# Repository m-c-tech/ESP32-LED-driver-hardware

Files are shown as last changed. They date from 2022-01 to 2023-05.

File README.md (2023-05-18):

# ESP32-LED-driver-hardware
A board to drive WRGB and addressable LEDs using a NodeMCU-32S ESP32 WiFi microcontroller development board.  

## Goals:
The goal for this project was to make an ESPHOME and Home Assistant compatible LED strip controller.  
Price is an important factor as well as ease of use and flexibility in its applications.  
[ESPHome](https://esphome.io/) is a software tool that can generate code for the ESP32 microcontrollers by using simple configuration files and [Home Assistant](https://www.home-assistant.io/) has a graphical interface to set up automations.  
This gives great flexibility with over-the-air updates and easy to understand setup.  
The ESP32 microcontroller is highly flexible with WiFi and bluetooth along with many GPIOs, ADCs, touch sensors, etc.  
Development boards for the ESP32 can be gotten for very cheap from various online sellers, pay close attention to the dev board pinouts as they can vary.  
This PCB design incorporates multiple resistor configurations to allow for differing types of LEDs to be driven, common anode, SPI, one wire.

## Software and costs:  
PCB design done in KICAD 6.0  
Mechanical enclosure design done in Autodesk Fusion 360.  
The bill of materials comes to roughly 20.70AUD per unit at quantaties of 20.  
This includes the ESP32 dev board ($6.75), components from digi-key ($7.80), PCBs from fab house ($2.27), 3D printer plastic ($1.60), plus a few other items.  

## Enclosure:  
Designed for 3D printing.  
Dimensions - (L) 56.6mm * (W) 56.6mm * (D) 26mm  
The enclosure needs a M3 heated nut-sert to be put in the lid and a countersunk M3 machine screw.  

## Power:  
Input power can be 5V to 12V up to 5A current.  
Input connector is a 2.1mm ID, 5.5mm OD, 9.5mm long barrel jack plug.  

## Pinouts:  
Pinout used for common anode RGBW 5/12V LEDs:  
VDD  - Power +ve  
IO19 - White  
IO18 - Red  
IO17 - Green  
IO16 - Blue  
GND	 - Unused  

Hardware changes for driving addressable LEDs:  
Remove 0R resistors from R1-R4.  
Place 0R resistors on R5-R7.  

Pinout for up to 4 strings of one wire addressable LEDs:  
VDD  - Power +ve (ensure your power supply is correct for your LED voltage)  
IO19 - LED data 1  
IO18 - LED data 2  
IO17 - LED data 3  
IO16 - LED data 4  
GND	 - GND  

Pinout used for 2 strings of SPI addressable LEDs:  
VDD  - Power +ve (ensure your power supply is correct for your LED voltage)  
IO19 - LED data 0  
IO18 - LED clock 0  
IO17 - LED data 1  
IO16 - LED clock 1  
GND	 - GND  

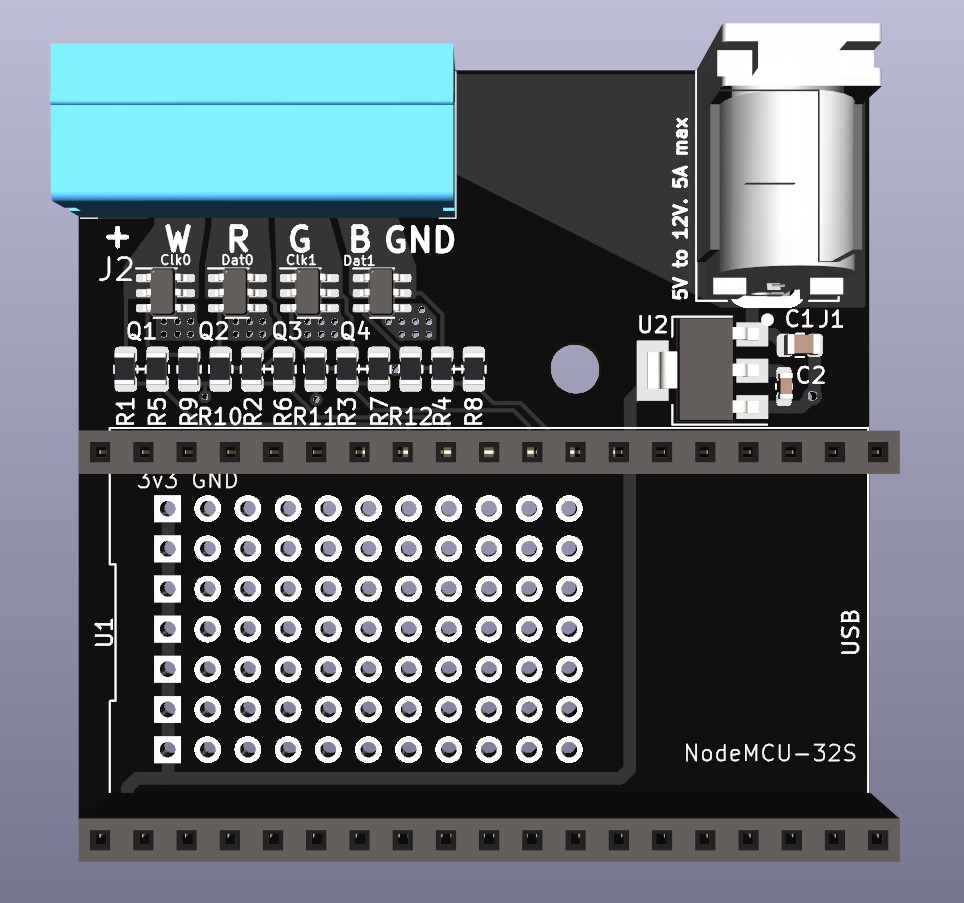
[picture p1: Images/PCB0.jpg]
PCB0

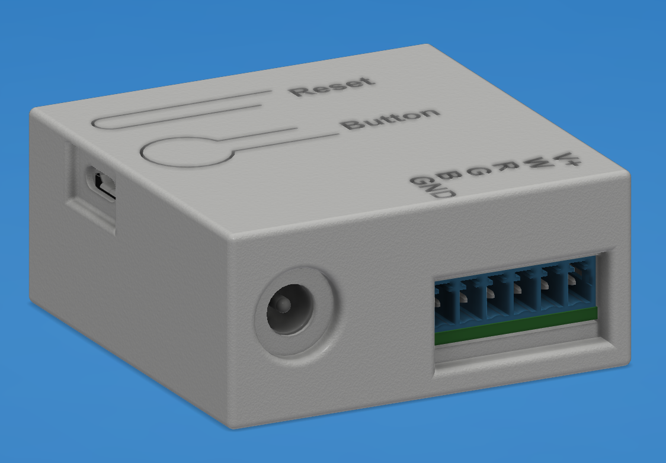
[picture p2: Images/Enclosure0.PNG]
Enclosure0

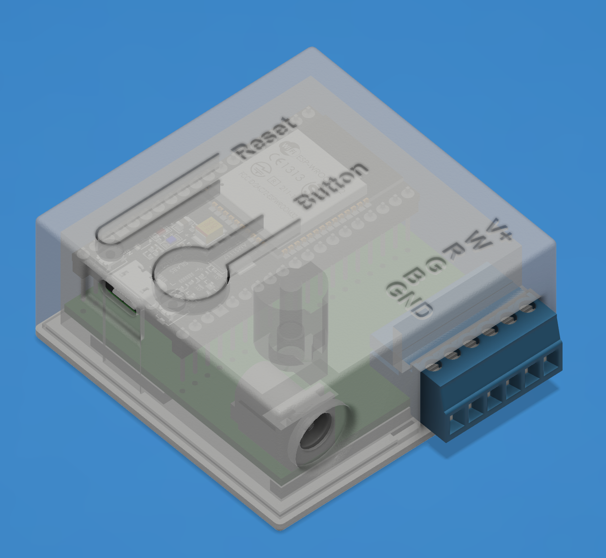
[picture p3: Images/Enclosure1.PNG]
Enclosure1


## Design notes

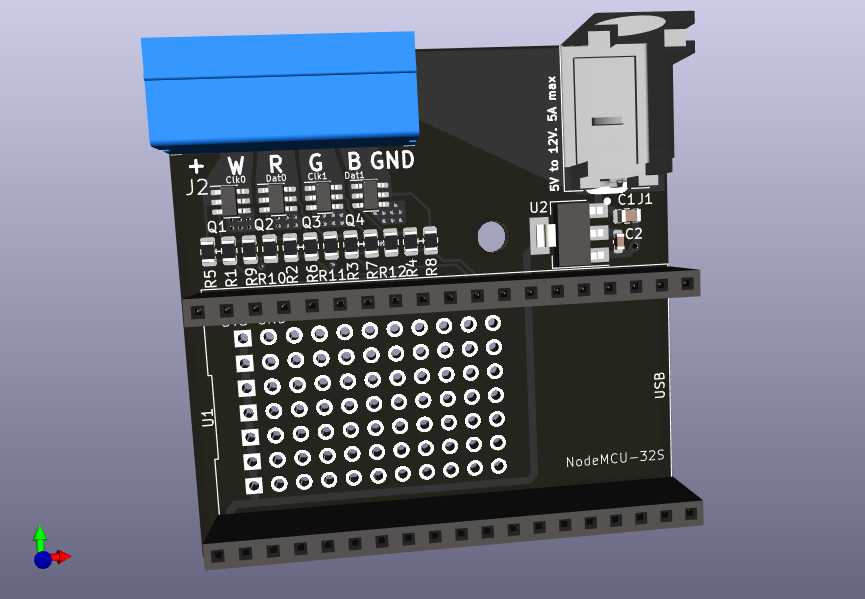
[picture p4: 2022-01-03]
ESP32-LED-driver-PCB/NodeMCU-32S-RGBWA-LED-driver.png

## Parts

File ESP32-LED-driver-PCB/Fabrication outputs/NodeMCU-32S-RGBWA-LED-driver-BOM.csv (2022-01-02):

Id | Designator | Package | Quantity | Designation | Supplier and ref
1 | R6,R7,R5 | R_0805_2012Metric | 3 | 0805 DNF
2 | R11,R8,R9,R10 | R_0805_2012Metric | 4 | 10k 0805
3 | JP3,JP2,JP1 | SolderJumper-2_P1.3mm_Open_TrianglePad1.0x1.5mm | 3 | SolderJumper_2_Open
4 | R2,R4,R3,R1 | R_0805_2012Metric | 4 | 0R 0805
5 | REF** | MountingHole_3.2mm_M3 | 1 | MountingHole_3.2mm_M3
6 | U2 | SOT-223-3_TabPin2 | 1 | NCP1117-3.3_SOT223
7 | Q1,Q2,Q4,Q3 | AO6404 | 4 | AO6404
8 | U1 | NodeMCU-32S | 1 | NodeMCU-32S
9 | C2 | C_0603_1608Metric | 1 | 10uF 6.3V
10 | C1 | C_0805_2012Metric | 1 | 10uF 25V
11 | J2 | CUI_TBP02R1-381-05BE | 1 | TBP02R1-381-05BE
12 | J1 | CUI_PJ-037A | 1 | PJ-037AH

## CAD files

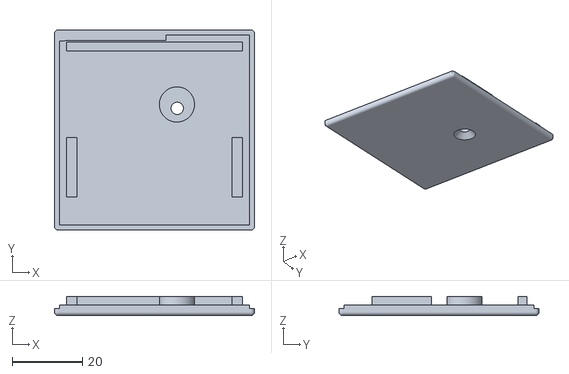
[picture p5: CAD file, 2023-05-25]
Enclosure/3D-model-exports/Baseplate.stl
56.8 x 56.8 x 5.40

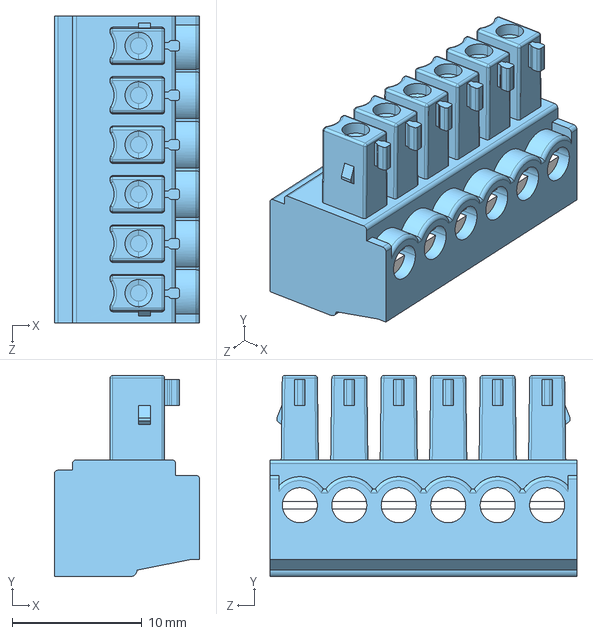
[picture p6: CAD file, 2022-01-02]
ESP32-LED-driver-PCB/3D model/CUI_DEVICES_TBP02P1-381-06BE.step
11.2 x 15.5 x 23.6 mm

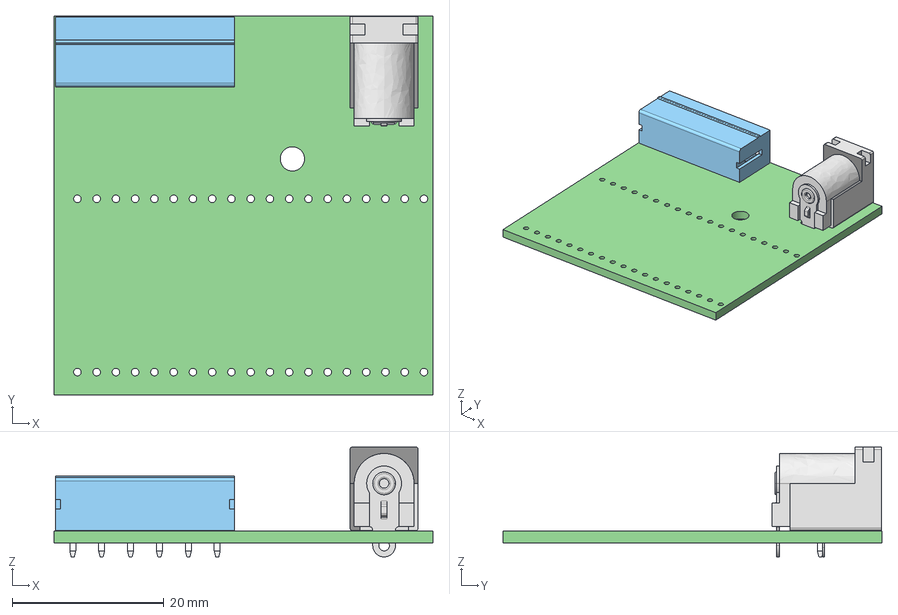
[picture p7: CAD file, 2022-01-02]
ESP32-LED-driver-PCB/NodeMCU-32S-RGBWA-LED-driver.step
50.0 x 50.0 x 14.5 mm
NodeMCU-32S-RGBWA-LED-driver PCB

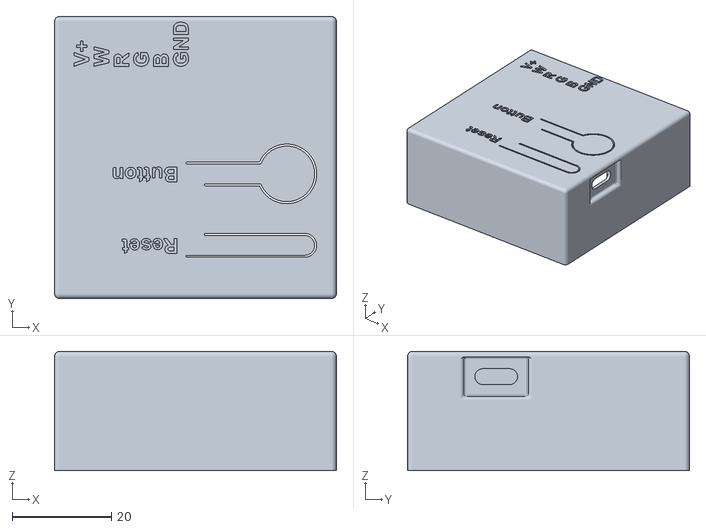
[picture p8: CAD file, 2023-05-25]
Enclosure/3D-model-exports/Top.stl
56.8 x 56.8 x 24.0

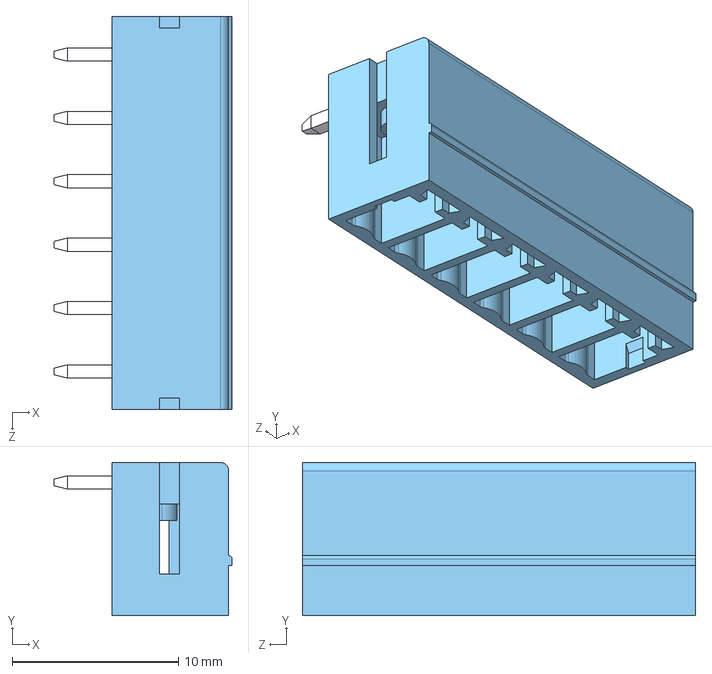
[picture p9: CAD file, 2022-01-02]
ESP32-LED-driver-PCB/3D model/CUI_DEVICES_TBP02R1-381-06BE.step
10.7 x 9.20 x 23.6 mm

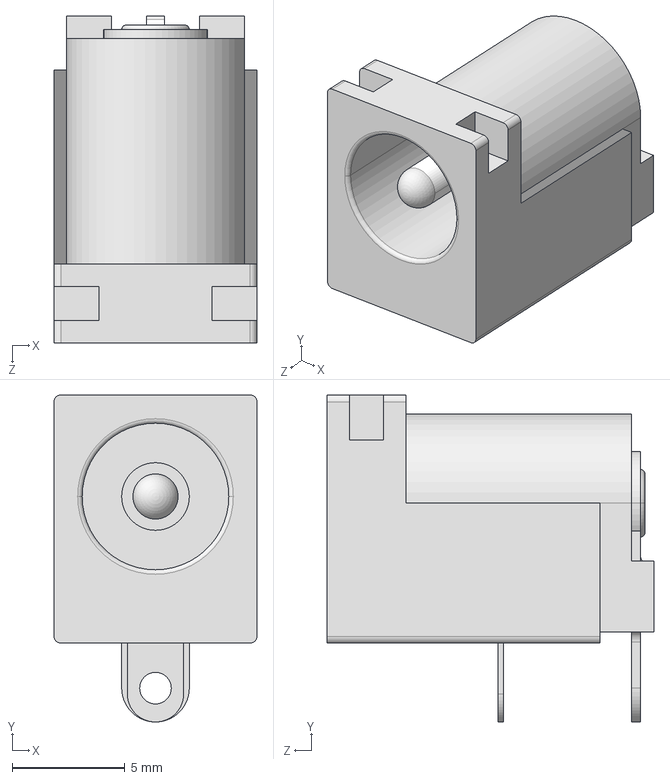
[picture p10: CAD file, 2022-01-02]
ESP32-LED-driver-PCB/3D model/CUI_DEVICES_PJ-037A.step
9.00 x 14.5 x 14.5 mm

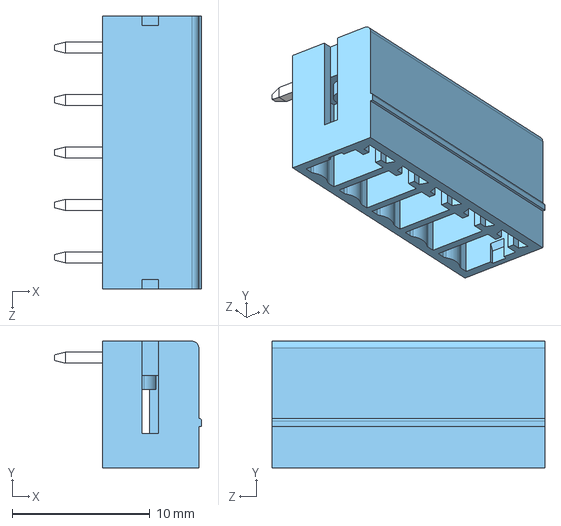
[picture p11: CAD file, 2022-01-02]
ESP32-LED-driver-PCB/3D model/CUI_DEVICES_TBP02R1-381-05BE.step
10.7 x 9.20 x 19.8 mm

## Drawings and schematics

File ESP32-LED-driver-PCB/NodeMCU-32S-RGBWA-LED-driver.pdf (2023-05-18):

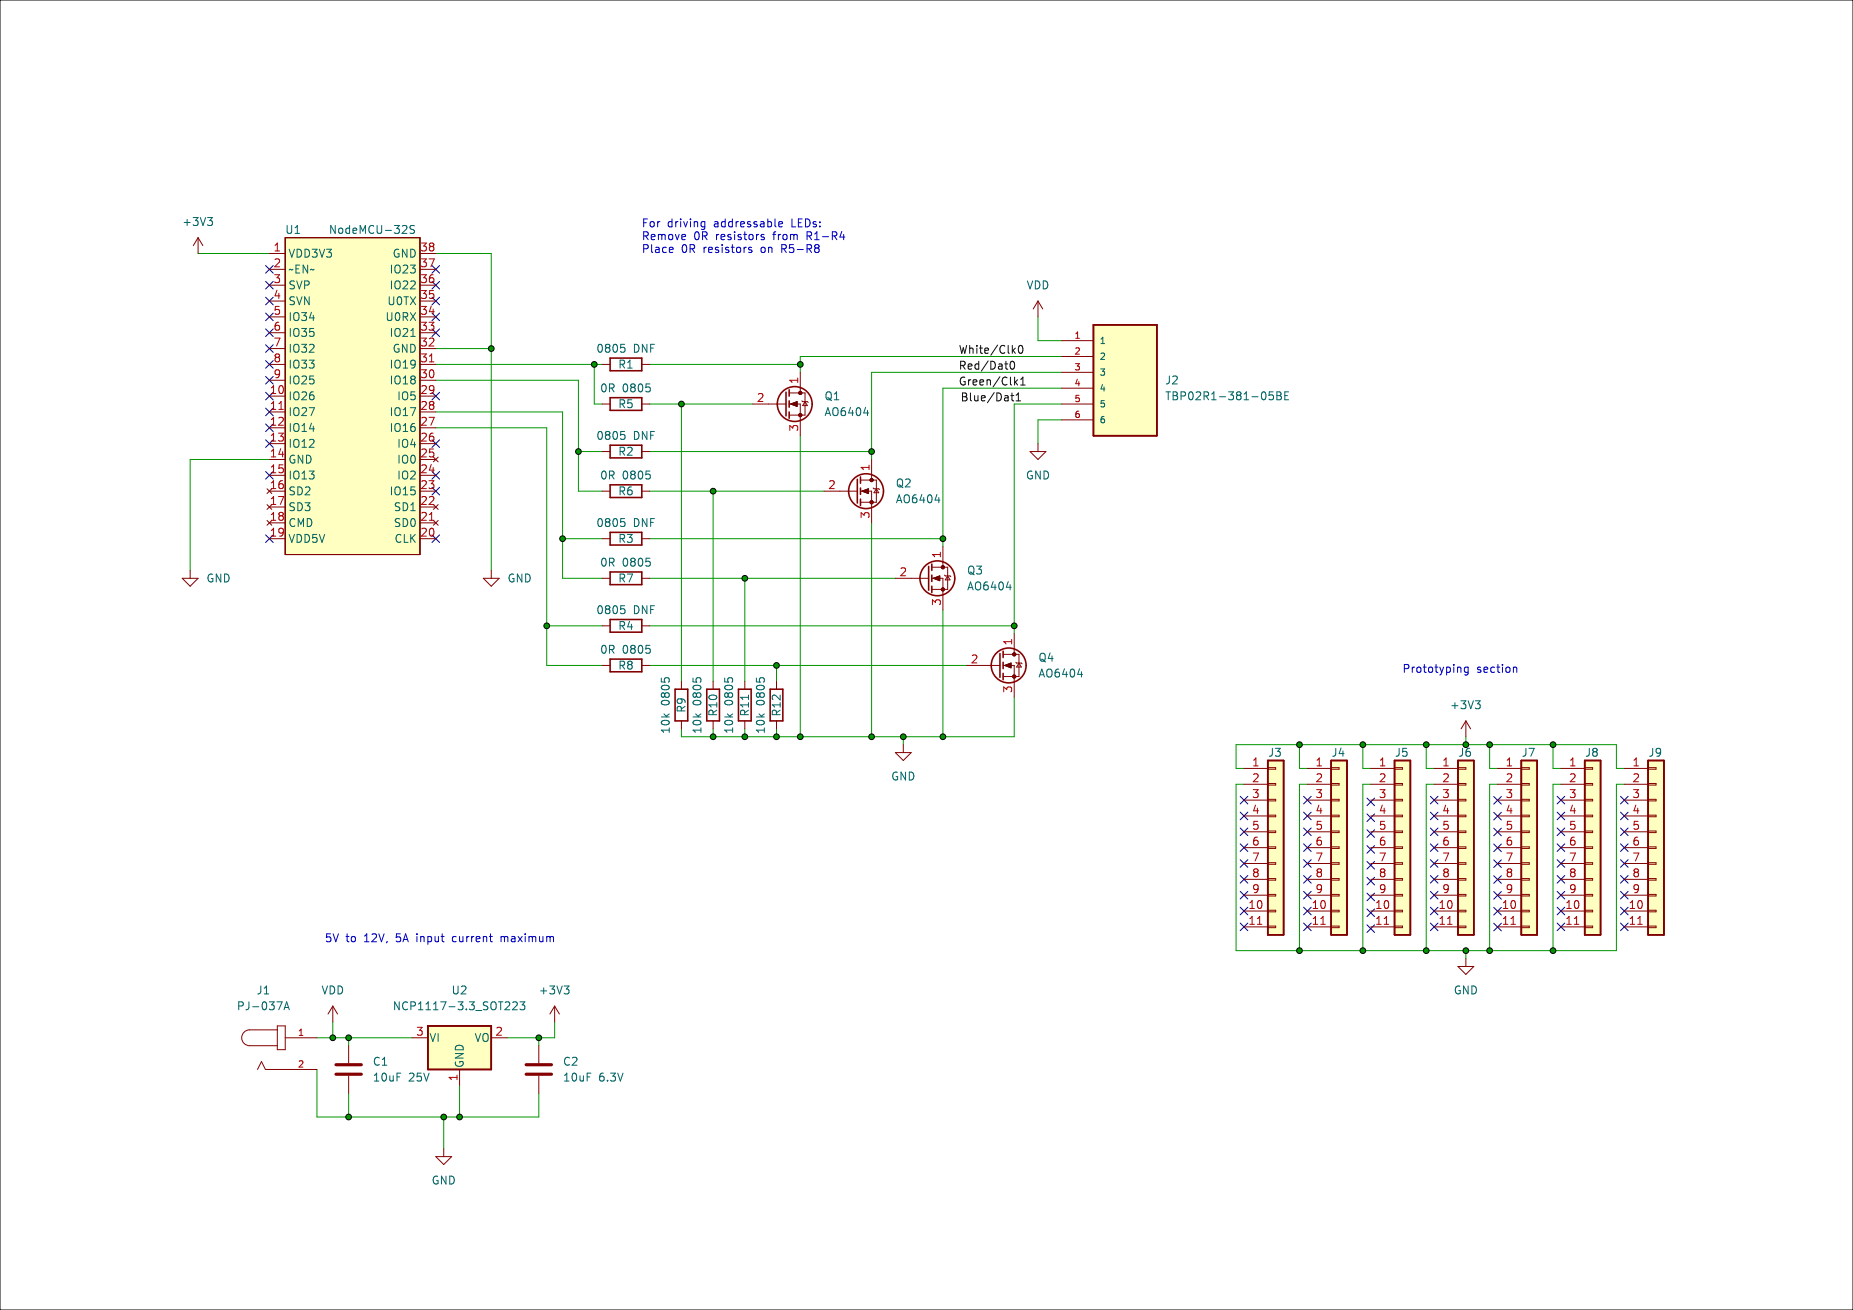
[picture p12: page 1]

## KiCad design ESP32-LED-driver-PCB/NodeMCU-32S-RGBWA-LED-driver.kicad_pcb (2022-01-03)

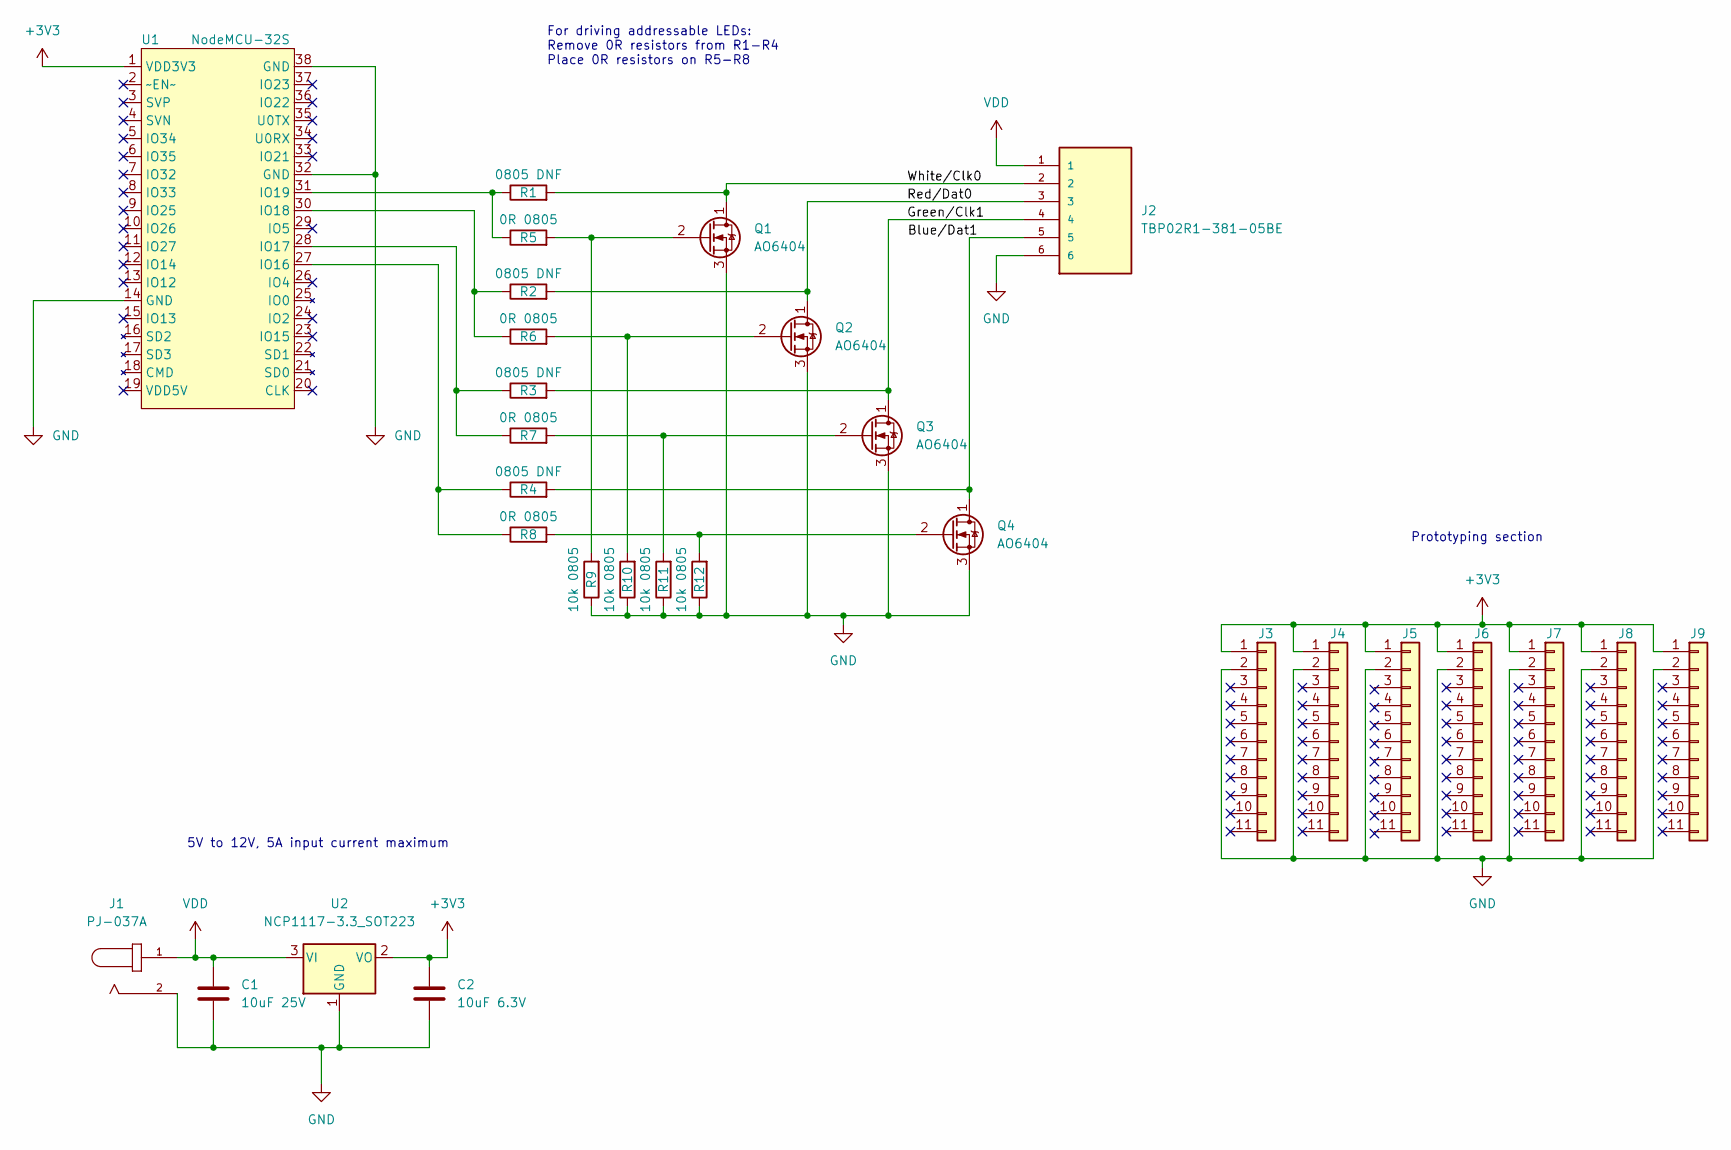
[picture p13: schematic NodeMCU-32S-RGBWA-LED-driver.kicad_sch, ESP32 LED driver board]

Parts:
C1: 10uF 25V; C_0805_2012Metric
C2: 10uF 6.3V; C_0603_1608Metric
J1: PJ-037A; CUI_PJ-037A
J2: TBP02R1-381-05BE; CUI_TBP02R1-381-06BE
J3, J4, J5, J6, J7, J8, J9: Conn_01x11; PinHeader_1x11_P2.54mm_Vertical
Q1, Q2, Q3, Q4: AO6404
R1, R2, R3, R4: 0805 DNF; R_0805_2012Metric
R5, R6, R7, R8: 0R 0805; R_0805_2012Metric
R9, R10, R11, R12: 10k 0805; R_0805_2012Metric
U1: NodeMCU-32S
U2: NCP1117-3.3_SOT223; SOT-223-3_TabPin2

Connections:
+3V3: C2.1, J3.1, J4.1, J5.1, J6.1, J7.1, J8.1, J9.1, U1.1 (VDD3V3), U2.2 (VO)
/Blue/Dat1: J2.5, Q4.1 (D), R4.2
/Green/Clk1: J2.4, Q3.1 (D), R3.2
/Red/Dat0: J2.3, Q2.1 (D), R2.2
/White/Clk0: J2.2, Q1.1 (D), R1.2
GND: C1.2, C2.2, J1.2, J2.6, J3.2, J4.2, J5.2, J6.2, J7.2, J8.2, J9.2, Q1.3 (S), Q2.3 (S), Q3.3 (S), Q4.3 (S), R9.1, R10.1, R11.1, R12.1, U1.14 (GND), U1.32 (GND), U1.38 (GND), U2.1 (GND)
unnamed: Q1.2 (G), R5.2, R9.2
unnamed: Q2.2 (G), R6.2, R10.2
unnamed: Q3.2 (G), R7.2, R11.2
unnamed: Q4.2 (G), R8.2, R12.2
unnamed: R4.1, R8.1, U1.27 (IO16)
unnamed: R3.1, R7.1, U1.28 (IO17)
unnamed: R2.1, R6.1, U1.30 (IO18)
unnamed: R1.1, R5.1, U1.31 (IO19)
VDD: C1.1, J1.1, J2.1, U2.3 (VI)

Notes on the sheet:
For driving addressable LEDs: Remove 0R resistors from R1-R4 Place 0R resistors on R5-R8
5V to 12V, 5A input current maximum
Prototyping section

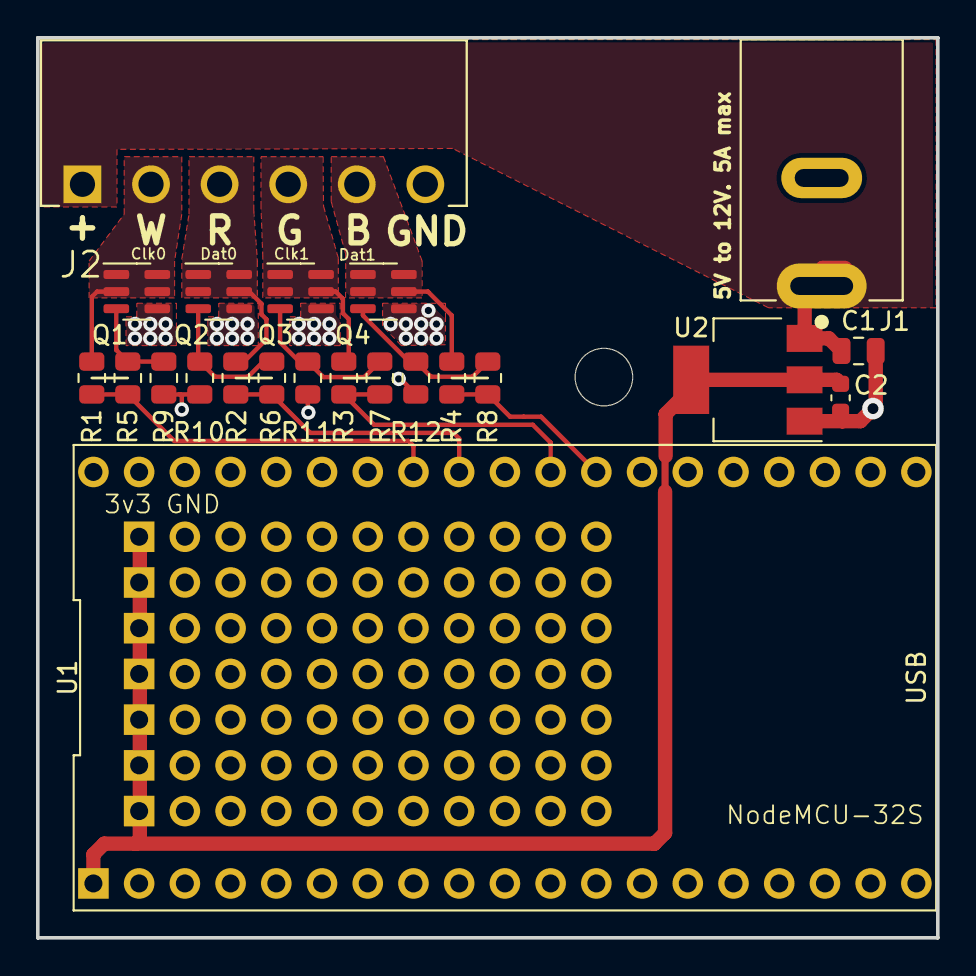
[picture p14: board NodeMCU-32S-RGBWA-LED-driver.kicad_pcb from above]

Board: 2 copper layers, 50.0 x 50.0 mm, 29 parts (0 on the bottom side), 15 nets.

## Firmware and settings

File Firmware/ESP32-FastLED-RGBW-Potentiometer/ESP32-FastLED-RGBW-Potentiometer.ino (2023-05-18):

#include <FastLED.h>

/*
 * This ESP32 code is created by esp32io.com
 *
 * This ESP32 code is released in the public domain
 *
 * For more detail (instruction and wiring diagram), visit https://esp32io.com/tutorials/esp32-potentiometer-fade-led
 */
extern const uint8_t gamma8[];

CRGBPalette16 gPal;

#define POTENTIOMETER_PIN  34  // ESP32 pin GIOP36 (ADC0) connected to Potentiometer pin
#define LED_PIN_R          18  // ESP32 pin GIOP21 connected to LED's pin
#define LED_PIN_G          17  
#define LED_PIN_B          16  
#define LED_PIN_W          19  

const int freq = 5000;
const int ledChannel_R = 0;
const int ledChannel_G = 1;
const int ledChannel_B = 2;
const int resolution = 8;

// Define the number of samples to keep track of. The higher the number, the
// more the readings will be smoothed, but the slower the output will respond to
// the input. Using a constant rather than a normal variable lets us use this
// value to determine the size of the readings array.
const int numReadings = 10;
int readings[numReadings];      // the readings from the analog input
int readIndex = 0;              // the index of the current reading
int total = 0;                  // the running total
int average = 0;                // the average

int inputPin = POTENTIOMETER_PIN;

void showAnalogRGB( const CRGB& rgb)
{
  ledcWrite(ledChannel_R, rgb.r);
  ledcWrite(ledChannel_G, rgb.g);
  ledcWrite(ledChannel_B, rgb.b);
}

// the setup routine runs once when you press reset:
void setup() {
  // initialize serial communication at 9600 bits per second:
  Serial.begin(9600);

  gPal = RainbowColors_p;

  for (int thisReading = 0; thisReading < numReadings; thisReading++) {
    readings[thisReading] = 0;
  }

  ledcSetup(ledChannel_R, freq, resolution);
  ledcSetup(ledChannel_G, freq, resolution);
  ledcSetup(ledChannel_B, freq, resolution);
  
  ledcAttachPin(LED_PIN_R, ledChannel_R);
  ledcAttachPin(LED_PIN_G, ledChannel_G);
  ledcAttachPin(LED_PIN_B, ledChannel_B);
  //ledcAttachPin(LED_PIN_W, ledChannel);
}

// the loop routine runs over and over again forever:
void loop() {
  
  // subtract the last reading:
  total = total - readings[readIndex];
  // read from the sensor:
  readings[readIndex] = analogRead(inputPin);
  // add the reading to the total:
  total = total + readings[readIndex];
  // advance to the next position in the array:
  readIndex = readIndex + 1;

  // if we're at the end of the array...
  if (readIndex >= numReadings) {
    // ...wrap around to the beginning:
    readIndex = 0;
  }

  // calculate the average:
  average = total / numReadings;
  // reads the input on analog pin A0 (value between 0 and 4095)

  // scales it to brightness (value between 0 and 255)
  int brightness = map(average, 4096, 0, 1, 240); //4096 max

  int brightness_gamma_corrected = pgm_read_byte(&gamma8[brightness]);


  
  static uint8_t hue;
  hue = hue + 1;
  // Use FastLED automatic HSV->RGB conversion
  if (brightness < 0) {
    showAnalogRGB( CHSV( hue, 255, 255) );
    delay(brightness);
  } else {
    //for (int i=0; i<=240; i+=1) {
      showAnalogRGB( CRGB(ColorFromPalette( gPal, brightness)));
      //delay(100);
    //}
  }
  

  /*
  // print out the value
  Serial.print("Analog value = ");
  Serial.print(average);
  Serial.print(" => brightness = ");
  Serial.println(brightness_gamma_corrected);
  delay(100);
  */
}

const uint8_t PROGMEM gamma8[] = {
    0,  0,  0,  0,  0,  0,  0,  0,  0,  0,  0,  0,  0,  0,  0,  0,
    0,  0,  0,  0,  0,  0,  0,  0,  0,  0,  0,  0,  1,  1,  1,  1,
    1,  1,  1,  1,  1,  1,  1,  1,  1,  2,  2,  2,  2,  2,  2,  2,
    2,  3,  3,  3,  3,  3,  3,  3,  4,  4,  4,  4,  4,  5,  5,  5,
    5,  6,  6,  6,  6,  7,  7,  7,  7,  8,  8,  8,  9,  9,  9, 10,
   10, 10, 11, 11, 11, 12, 12, 13, 13, 13, 14, 14, 15, 15, 16, 16,
   17, 17, 18, 18, 19, 19, 20, 20, 21, 21, 22, 22, 23, 24, 24, 25,
   25, 26, 27, 27, 28, 29, 29, 30, 31, 32, 32, 33, 34, 35, 35, 36,
   37, 38, 39, 39, 40, 41, 42, 43, 44, 45, 46, 47, 48, 49, 50, 50,
   51, 52, 54, 55, 56, 57, 58, 59, 60, 61, 62, 63, 64, 66, 67, 68,
   69, 70, 72, 73, 74, 75, 77, 78, 79, 81, 82, 83, 85, 86, 87, 89,
   90, 92, 93, 95, 96, 98, 99,101,102,104,105,107,109,110,112,114,
  115,117,119,120,122,124,126,127,129,131,133,135,137,138,140,142,
  144,146,148,150,152,154,156,158,160,162,164,167,169,171,173,175,
  177,180,182,184,186,189,191,193,196,198,200,203,205,208,210,213,
  215,218,220,223,225,228,231,233,236,239,241,244,247,249,252,255 };

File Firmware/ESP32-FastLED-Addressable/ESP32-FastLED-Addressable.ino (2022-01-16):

#include <FastLED.h>

// How many leds in your strip?
#define NUM_LEDS 285
#define MIM_LEDS 205

// For led chips like Neopixels, which have a data line, ground, and power, you just
// need to define DATA_PIN.  For led chipsets that are SPI based (four wires - data, clock,
// ground, and power), like the LPD8806 define both DATA_PIN and CLOCK_PIN
#define DATA_PIN 18
#define CLOCK_PIN 19

// Define the array of leds
CRGB leds[NUM_LEDS];


#define ONBOARD_LED  1

void setup() {
  pinMode(ONBOARD_LED,OUTPUT);
  
  // Uncomment/edit one of the following lines for your leds arrangement.
  // FastLED.addLeds<TM1803, DATA_PIN, RGB>(leds, NUM_LEDS);
  // FastLED.addLeds<TM1804, DATA_PIN, RGB>(leds, NUM_LEDS);
  // FastLED.addLeds<TM1809, DATA_PIN, RGB>(leds, NUM_LEDS);
  // FastLED.addLeds<WS2811, DATA_PIN, RGB>(leds, NUM_LEDS);
  // FastLED.addLeds<WS2812, DATA_PIN, RGB>(leds, NUM_LEDS);
  // FastLED.addLeds<WS2812B, DATA_PIN, RGB>(leds, NUM_LEDS);
  // FastLED.addLeds<NEOPIXEL, DATA_PIN>(leds, NUM_LEDS);
  // FastLED.addLeds<APA104, DATA_PIN, RGB>(leds, NUM_LEDS);
  // FastLED.addLeds<UCS1903, DATA_PIN, RGB>(leds, NUM_LEDS);
  // FastLED.addLeds<UCS1903B, DATA_PIN, RGB>(leds, NUM_LEDS);
  // FastLED.addLeds<GW6205, DATA_PIN, RGB>(leds, NUM_LEDS);
  // FastLED.addLeds<GW6205_400, DATA_PIN, RGB>(leds, NUM_LEDS);

  // FastLED.addLeds<WS2801, RGB>(leds, NUM_LEDS);
  // FastLED.addLeds<SM16716, RGB>(leds, NUM_LEDS);
  // FastLED.addLeds<LPD8806, RGB>(leds, NUM_LEDS);
  // FastLED.addLeds<P9813, RGB>(leds, NUM_LEDS);
  // FastLED.addLeds<APA102, RGB>(leds, NUM_LEDS);
  // FastLED.addLeds<DOTSTAR, RGB>(leds, NUM_LEDS);

  // FastLED.addLeds<WS2801, DATA_PIN, CLOCK_PIN, RGB>(leds, NUM_LEDS);
  // FastLED.addLeds<SM16716, DATA_PIN, CLOCK_PIN, RGB>(leds, NUM_LEDS);
  // FastLED.addLeds<LPD8806, DATA_PIN, CLOCK_PIN, RGB>(leds, NUM_LEDS);
  // FastLED.addLeds<P9813, DATA_PIN, CLOCK_PIN, RGB>(leds, NUM_LEDS);
  FastLED.addLeds<APA102, DATA_PIN, CLOCK_PIN, BGR>(leds, NUM_LEDS);
  // FastLED.addLeds<DOTSTAR, DATA_PIN, CLOCK_PIN, RGB>(leds, NUM_LEDS);
}

void loop() {
  static uint8_t hue = 0;
//  Serial.print("x");
  // First slide the led in one direction
  for(int i = 0; i < NUM_LEDS; i++) {
    // Set the i'th led to red
    leds[i] = CHSV(hue, 255, 255);
    // Show the leds
    // now that we've shown the leds, reset the i'th led to black
    // leds[i] = CRGB::Black;
    // Wait a little bit before we loop around and do it again
  }
  FastLED.show();
  delay(10);
  hue += 1;

  // flash the internal LED
  if (hue % 5 < 4) {
    digitalWrite(ONBOARD_LED,HIGH);
  } else {
    digitalWrite(ONBOARD_LED,LOW);
  }
}

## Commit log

2022-01-02 First commit of all files
    Hardware layout has gone through a few revisions already. Should be okay to send to the PCB factory
    [Baseplate.stl, CUI_DEVICES_PJ-037A.step, CUI_DEVICES_TBP02R1-381-05BE.step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]
2022-01-02 Re-organising folders
    Re-organising folders
    [Baseplate.stl, CUI_DEVICES_PJ-037A.step, CUI_DEVICES_TBP02R1-381-05BE.step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]
2022-01-02 Project description
    [NodeMCU-32S-RGBWA-LED-driver.kicad_pcb]
2022-01-02 Updated silkscreen
    [NodeMCU-32S-RGBWA-LED-driver-B_Cu.gbr, NodeMCU-32S-RGBWA-LED-driver-B_Mask.gbr, NodeMCU-32S-RGBWA-LED-driver-B_Paste.gbr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]
2022-01-02 Updated to 6 pin connector
    Moved to 6 pin connector to get more addressable outputs with a dedicated ground pin.
    [CUI_DEVICES_TBP02P1-381-06BE.step, CUI_DEVICES_TBP02R1-381-06BE.step, NodeMCU-32S-RGBWA-LED-driver.kicad_pcb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]
2022-01-03 Added prototyping area
    Added prototyping area to allow for extra sensors.
    Updated some silkscreen
    [NodeMCU-32S-RGBWA-LED-driver-B_Cu.gbr, NodeMCU-32S-RGBWA-LED-driver-B_Mask.gbr, NodeMCU-32S-RGBWA-LED-driver-B_Paste.gbr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]
2022-01-03 Updated enclosure for 6 pin device
2022-01-06 Updated screw clearances and heat-sert dimensions
    [Baseplate.stl, Top.stl]
2022-01-06 Fixed last commit
    [Baseplate.stl, Top.stl]
2022-01-16 💡 Add LED Tester Firmware
2023-05-18 Updated documentation
    Schematics pdf and README referenced an older version of the schematics. Updated to remove these references.
2023-05-23 Modified enclosure
    Fixed an incorrect heat insert diameter
    Updated the fusion 360 project
    [Baseplate.stl, Top.stl]
2023-05-24 Updated enclosure
    Enclosure updated with better PCB supports and flexible buttons
2023-05-25 Updated enclosure buttons
    Made the buttons easier to push
    [Baseplate.stl, Top.stl]
